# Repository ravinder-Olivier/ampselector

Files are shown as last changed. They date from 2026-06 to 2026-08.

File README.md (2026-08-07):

# Ampselector (Guitar Rig 7 centric macropad)
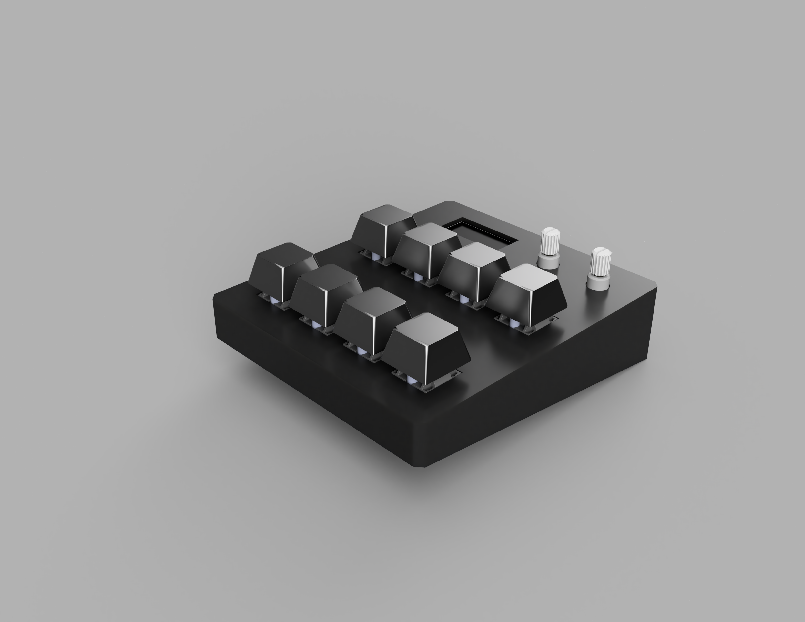
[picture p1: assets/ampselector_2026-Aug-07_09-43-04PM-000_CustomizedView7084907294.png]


Ampselector is a 8 key + two encoder macropad designed to be used for Guitar Rig 7. For actions such as switching between amps or effects presets.

Built using a RP2040 microcontroller in the form of the SEEED STUDIO XIAO, and powered by custom software built on QMK.

## Features: 
- 4x2 grid array
- Dual EC11 microcontrollers
- OLED Display
- Natively outputs MIDI CC codes, and can be programmed into GR7

## CAD / Assembly
- The PCB is screwed *(M3 screw)* onto the lower case with two screws *(into heatset inserts)*
- The top panel is super glued onto the lower case *(sleeker look)*
- Uses MX style keys and keycaps
- This was designed in Fusion360
- Make sure to flash firmware and have it running before you superglue the case together!

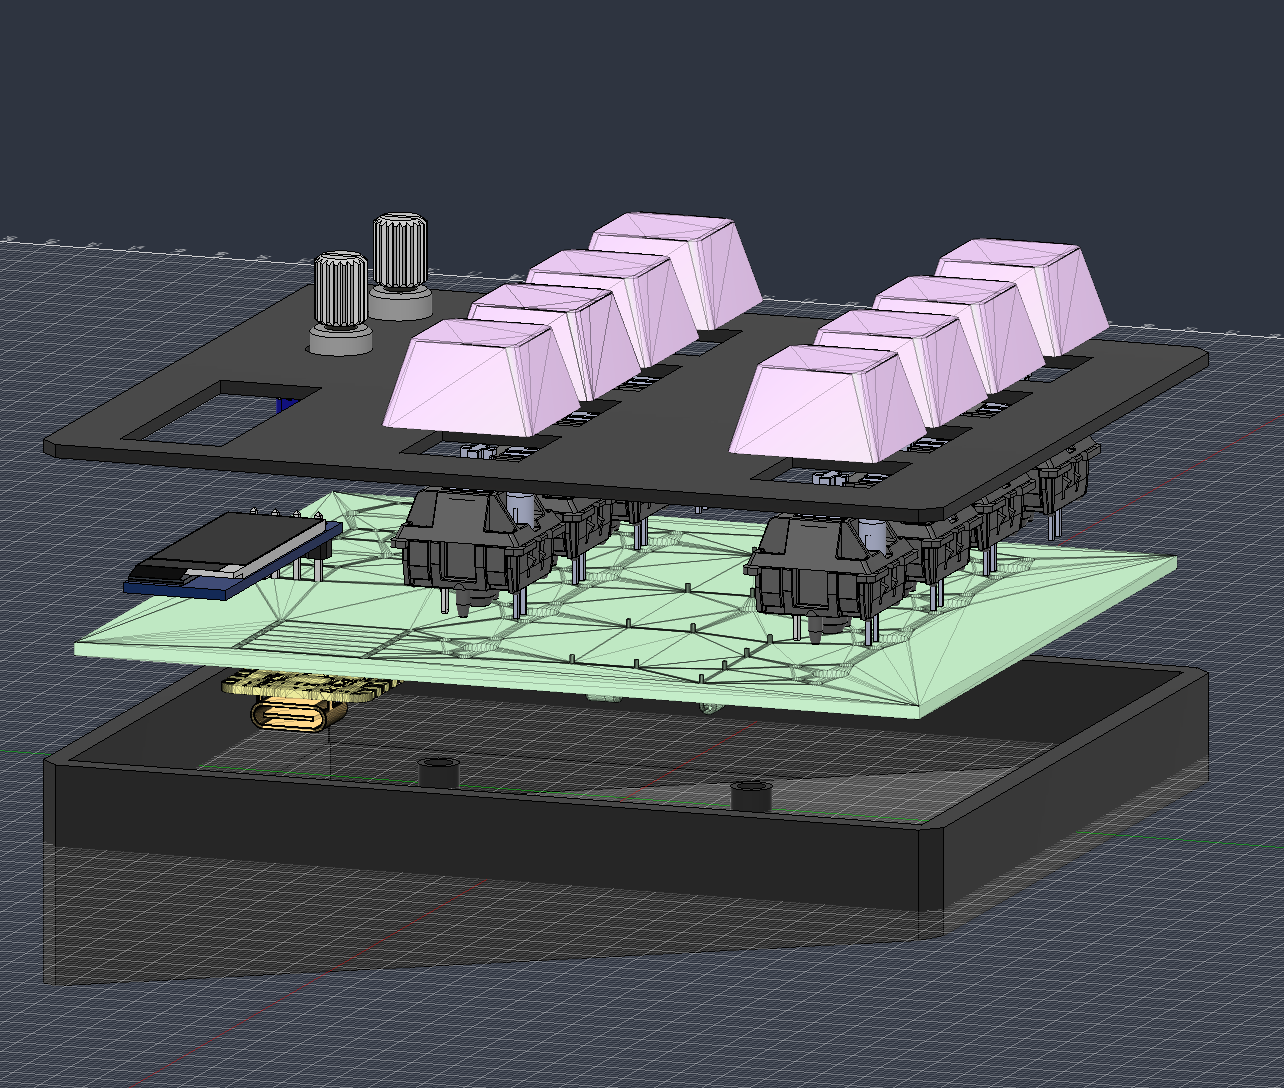
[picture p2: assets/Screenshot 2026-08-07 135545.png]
Screenshot 2026-08-07 135545.png

(note that usb port cutout is not visible in the first image)
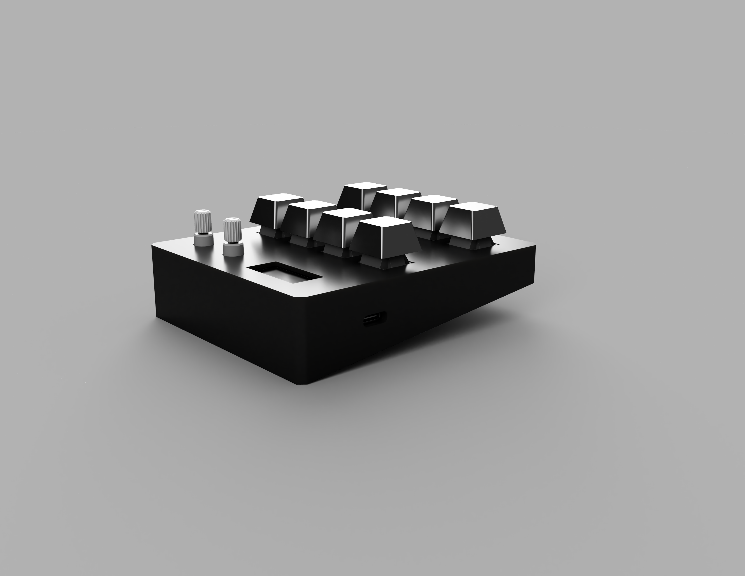
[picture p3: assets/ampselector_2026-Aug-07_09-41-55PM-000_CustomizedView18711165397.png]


## PCB 
- I would recommend buying a thicker style of 2 layer PCB for this project, for the added durability and rigidity
- This was designed in KiCad 

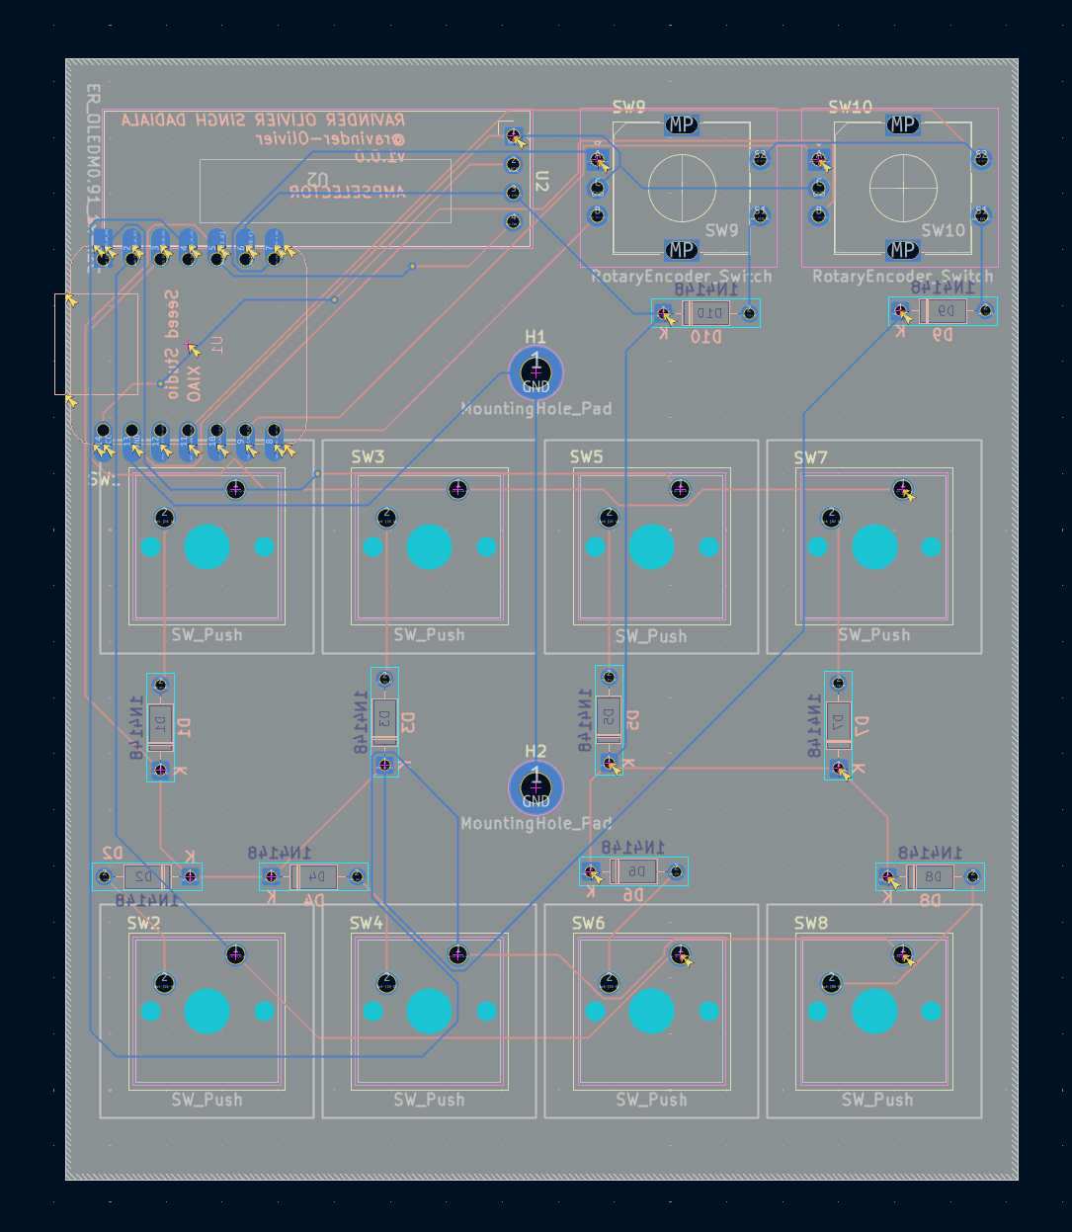
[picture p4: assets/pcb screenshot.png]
pcb screenshot.png

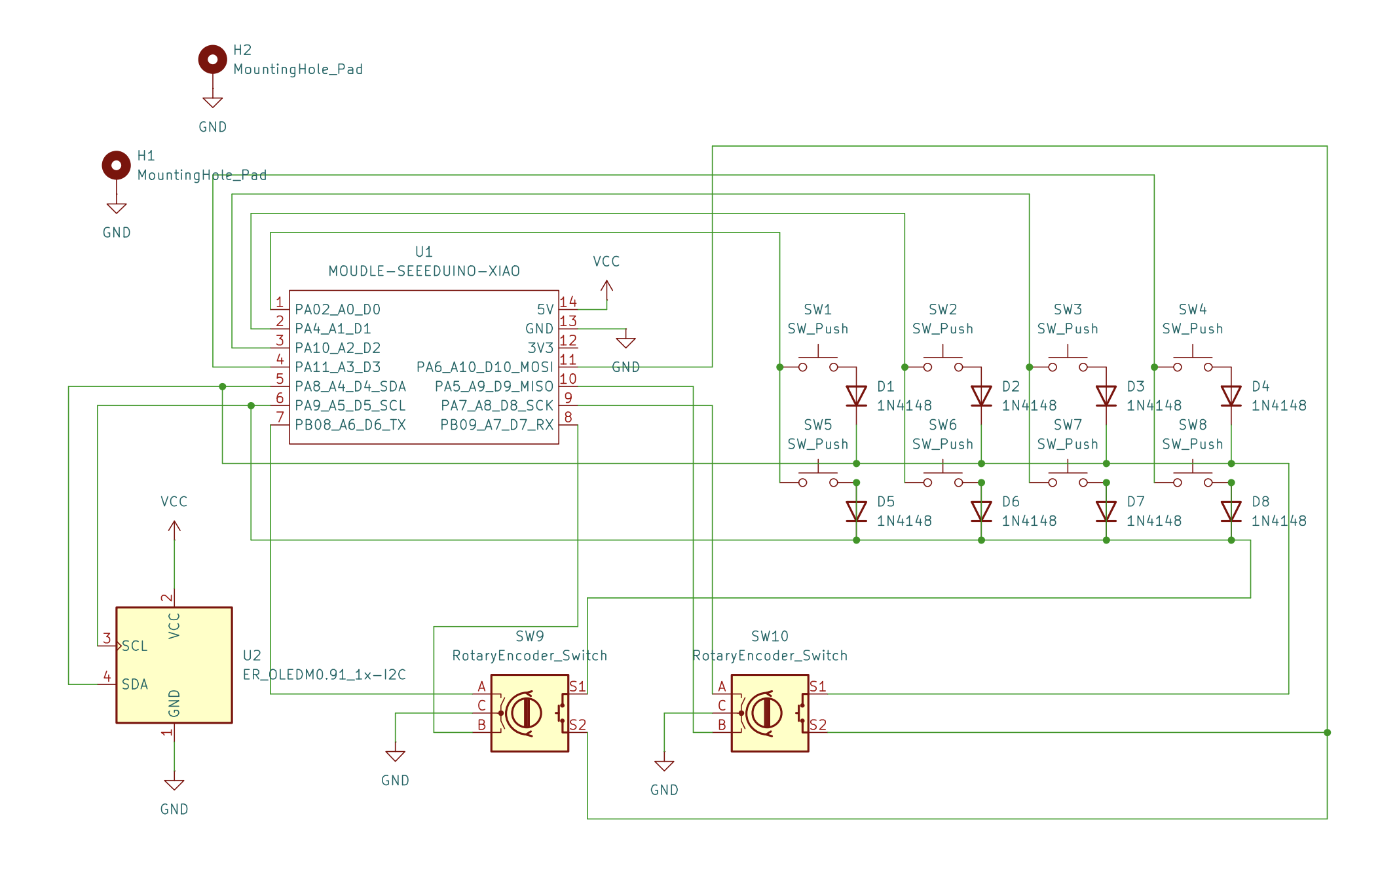
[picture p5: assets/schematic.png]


## BILL OF MATERIALS (BOM)
This project uses:
- 1x Seeed Studio XIAO RP2040
- 8x through hole 1N4148 diodes
- 1x OLED Display (.91in)
- 2x EC11 Rotarary Encoders
- 8x MX Style Keyswitches
- 8x DSA Keycaps
- 2x M3 x 16mm Screws
- 2x M3 Heatset inserts
- 1x PCB (order with gerbers.zip in production)
- 1x Top case (3d print  file in production)
- 1x Bottom case (3d print  file in production)

## Flashing firmware:
- Download the "firmware.uf2" file
- Press and hold the BOOT button on the RP2040 board
- Connect the Data compatible USB cable to the board
- It will appear like a USB drive on your computer, drop the "firmware.uf2" file onto it
- Once it uploads it should disappear as a USB drive, and restart and begin running the QMK firmware!

## Mapping to Guitar Rig 7:
- The keyboard will output various MIDI CC codes, which you can map to various functions in GR7. There's some good info on this forum [thread](https://community.native-instruments.com/discussion/46400/guitar-rig-7-switching-presets-live-with-a-midi-foot-controller)

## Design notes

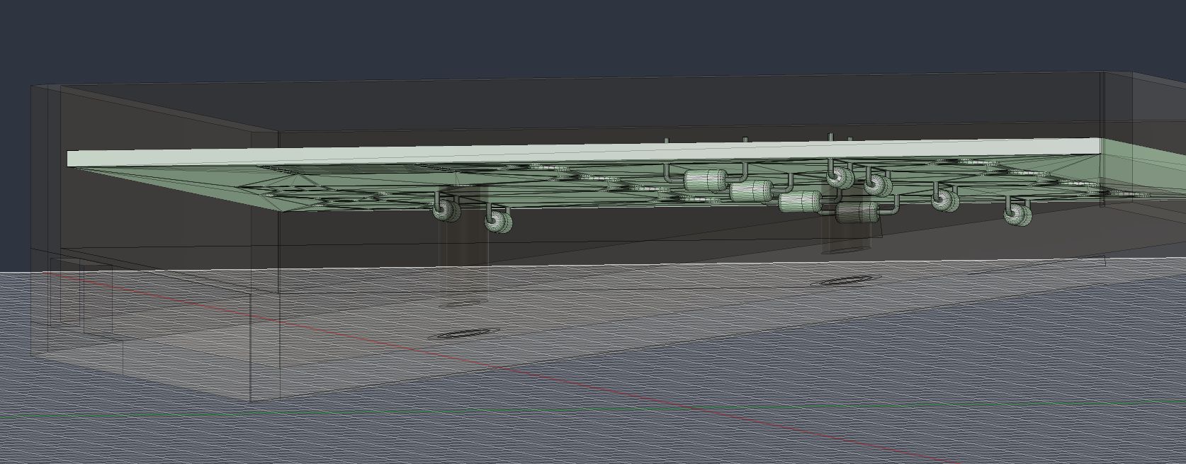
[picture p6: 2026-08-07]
assets/Screenshot 2026-08-07 143020.png

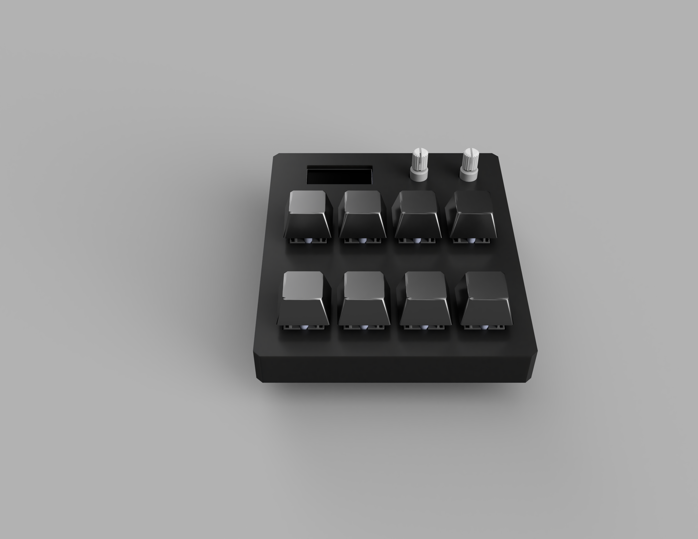
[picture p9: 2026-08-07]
assets/bc9d5303-fcb5-4f72-8860-90336da642d3.PNG

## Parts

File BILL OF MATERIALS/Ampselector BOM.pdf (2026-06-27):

Category | PART | QUANTITY | NOTES
Microcontroller | Seeed Studio XIAO RP2040 | 1
Diodes - through hole | 1N4148 | 8
Display | .91 inch oled display | 1
Encoder | ec11 encoder | 2
Switches | MX style keyswitches | 8
Keycaps | DSA keycaps | 8
Heatset inserts | M3 heatset insert | 2
Screws | m3x16mm screw | 2
Case | Top case | 1 | 3D PRINT
Case | Bottom case | 1 | 3D PRINT
PCB | Ampselector PCB | 1 | Purchase Custom PCB from PCB manufacturer

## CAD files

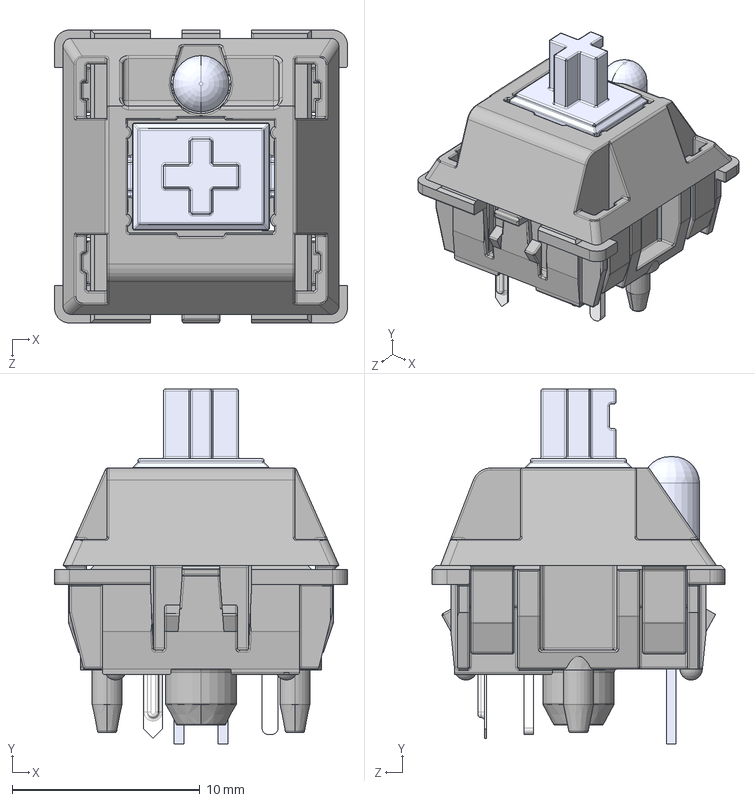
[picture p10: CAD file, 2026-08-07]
CAD/assets/cherry-mx-switch-5.snapshot.2/MX .STEP
15.6 x 18.9 x 15.6 mm
MX 轴 按键′_ü___¨1
MX 轴 轴体áì_¨￠¨__
MX粣 拸簽LEDLEDLED
MX轴 轴体 底部 μ×2__默认_á2____è_
针脚___默认__è_

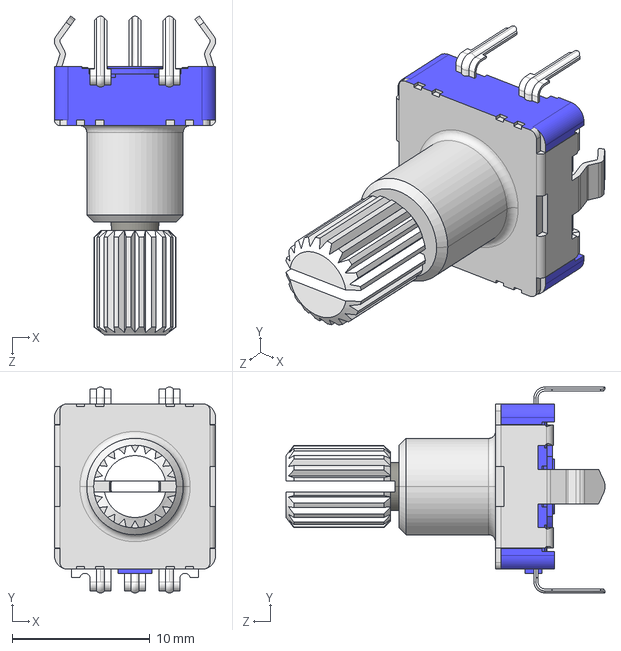
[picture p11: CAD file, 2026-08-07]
CAD/assets/ec11-rotary-encoder-dode-switch-15mm-1.snapshot.1/EC11 Rotary Encoder Dode Switch-15mm .STEP
11.7 x 15.0 x 23.2 mm

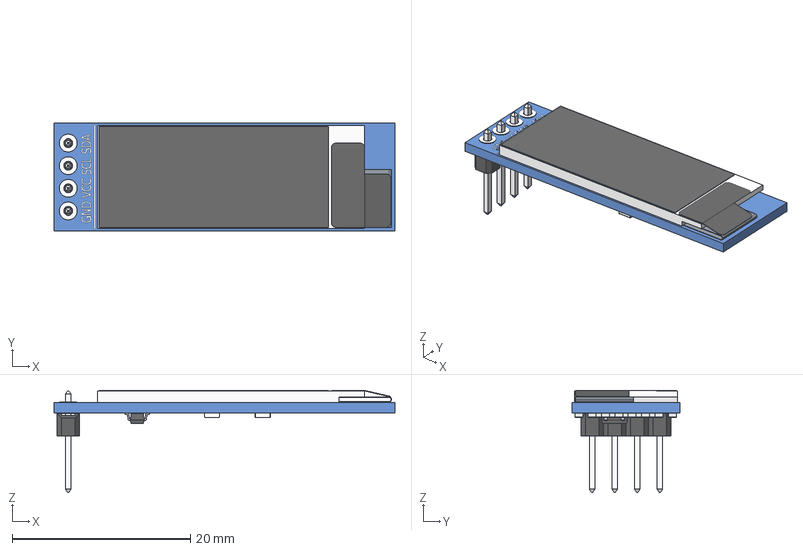
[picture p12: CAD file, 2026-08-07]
CAD/assets/OLED_0.91_128x32.stp
38.3 x 12.1 x 11.5 mm
OLED_0.91_128x32
Pin Header 4 x 1 TH 2.54mm Pitch
RESC-0603 x 13
2SD0601A

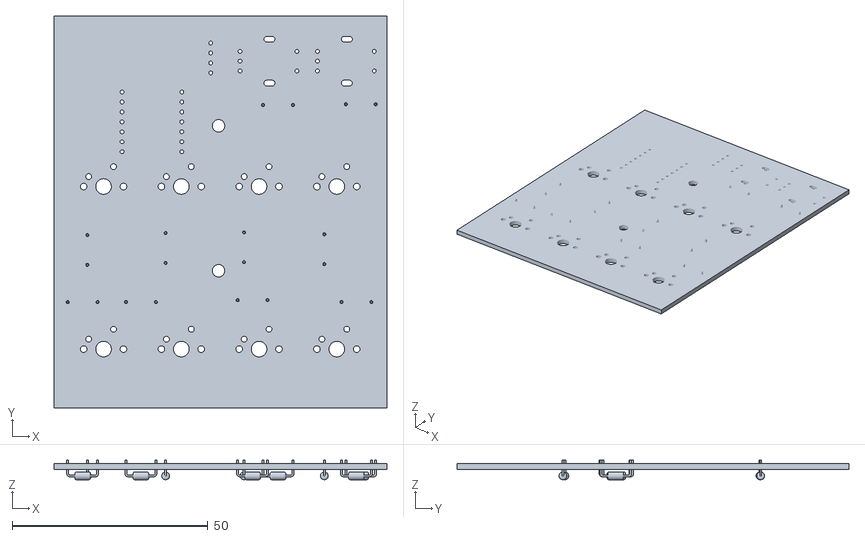
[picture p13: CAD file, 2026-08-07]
CAD/PCB.stl
85.0 x 100.0 x 5.01

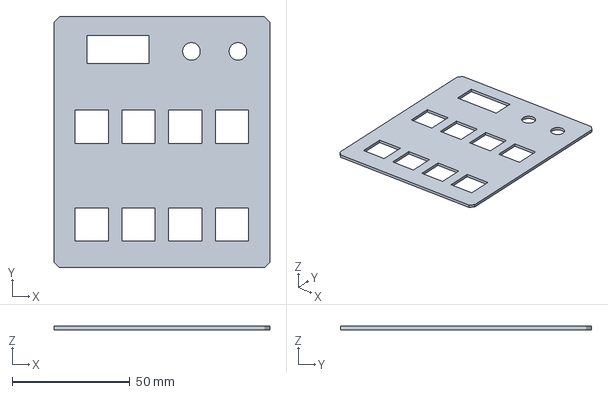
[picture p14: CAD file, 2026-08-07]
Production/Upper Panel.3mf
91.6 x 106.6 x 1.50 mm

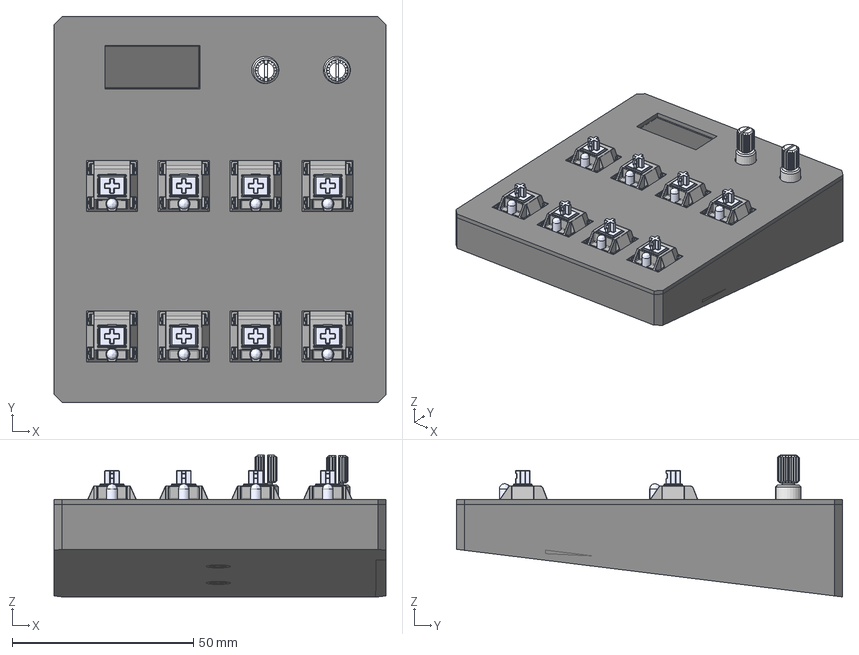
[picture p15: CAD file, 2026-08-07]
CAD/ampselector.step
91.6 x 106.6 x 39.1 mm
Ðý×ª±àÂëÆ÷EC11 E-05SW x 2
MX Öá °´¼ü¡ä_¨¹ ___¡§1 x 8
MX Öá ÖáÌå¨¢¨¬ _¡§¡é¡§__ x 8
MXÖá ÎÞÃ±LEDLEDLED x 8
MXÖá ÖáÌå µ×²¿ ¦Ì¡ Á2__Ä¬ÈÏ_¨¢2____¨¨_ x 8
Õë½Å___Ä¬ÈÏ__¨¨ _ x 8
OLED_0.91_128x32
Pin Header 4 x 1 TH 2.54mm Pitch
RESC-0603 x 13
2SD0601A

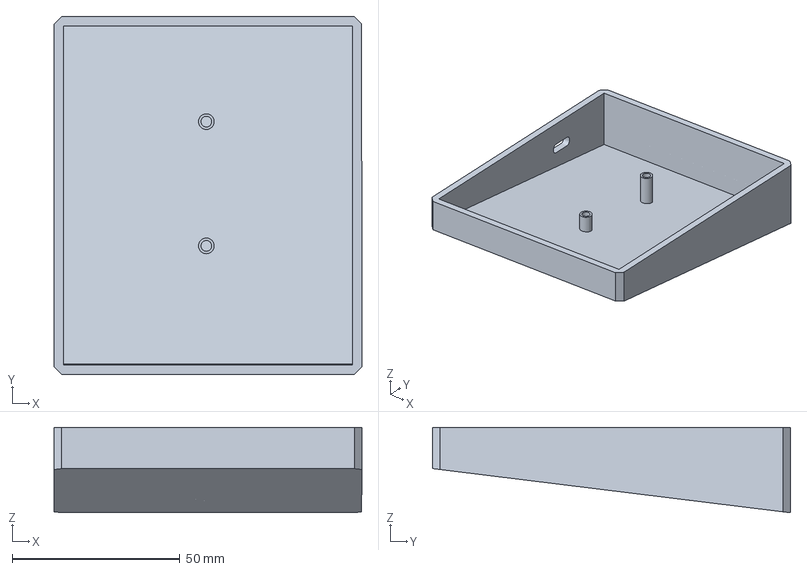
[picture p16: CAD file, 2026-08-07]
Production/Lower Case.3mf
91.6 x 106.6 x 25.4 mm

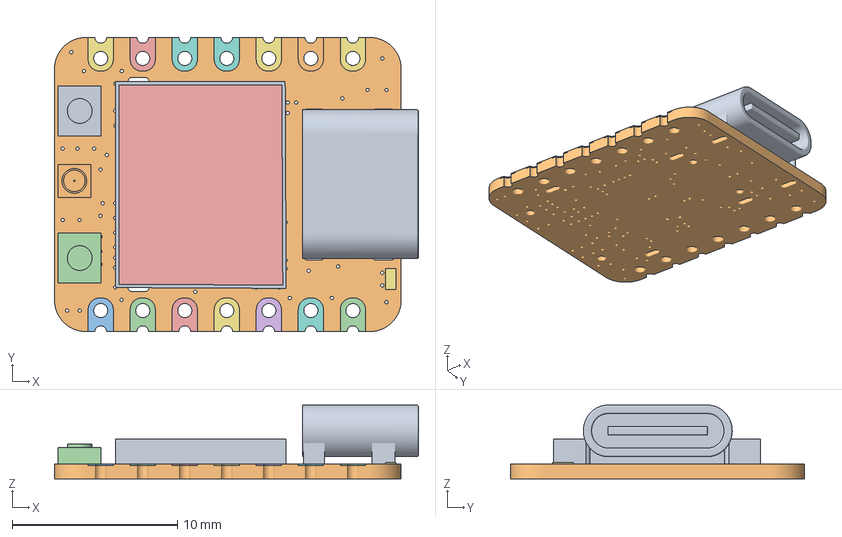
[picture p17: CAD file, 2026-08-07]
CAD/assets/Seeed Studio XIAO ESP32C3.3mf
22.0 x 17.8 x 4.47 mm
Button_B_(Boot?)
C0201
L0201
Button_A_(Reset)
PMOS_1.0*0.6*0.35MM
R0201
SOT-25
USB-C_terminal
R0201_(2)
R0201_(3)
SOD-523
F0603
C0201_(2)
SOT-25_(2)
X2-SMD-1.6X1.0X0.5MM
C0201_(3)
L0201_(2)
C0201_(4)
LED-0402
R0201_(4)
C0201_(5)
C0201_(6)
C0201_(7)
R0201_(5)
C0201_(8)
QFN32G-0.5-5X5MM
C0201_(9)
C0201_(10)
C0201_(11)
C0201_(12)
C0201_(13)
C0201_(14)
R0201_(6)
C0201_(15)
C0201_(16)
R0201_(7)
C0201_(17)
C0201_(18)
C0201_(19)
R0201_(8)
C0201_(20)
C0201_(21)
C0201_(22)
X4-SMD-2.0X1.6X0.5MM
C0201_(23)
C0201_(24)
C0201_(25)
R0201_(9)
C0201_(26)
C0201_(27)
R0201_(10)
C0201_(28)
R0201_(11)
R0201_(12)
R0201_(13)
R0201_(14)
Board

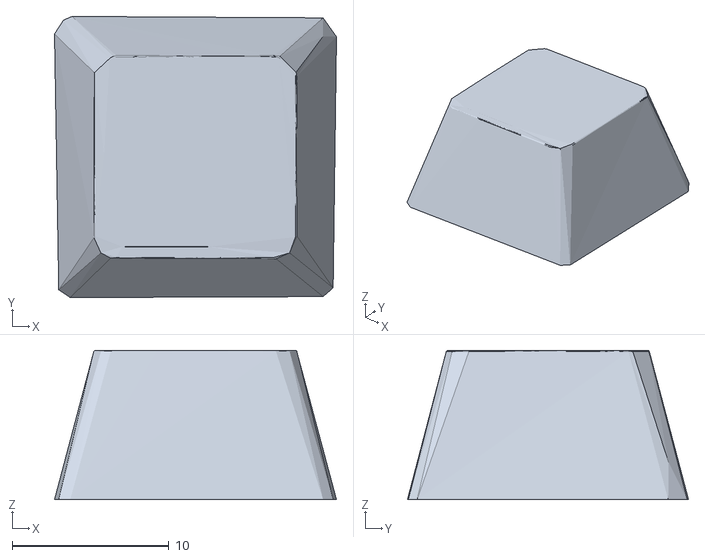
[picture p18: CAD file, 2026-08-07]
CAD/assets/Simple-CherryMX-Keycap.stl
18.0 x 17.9 x 9.50

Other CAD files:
CAD/assets/newpcb.step
CAD/ampselector.f3z
CAD/assets/newpcb.stl

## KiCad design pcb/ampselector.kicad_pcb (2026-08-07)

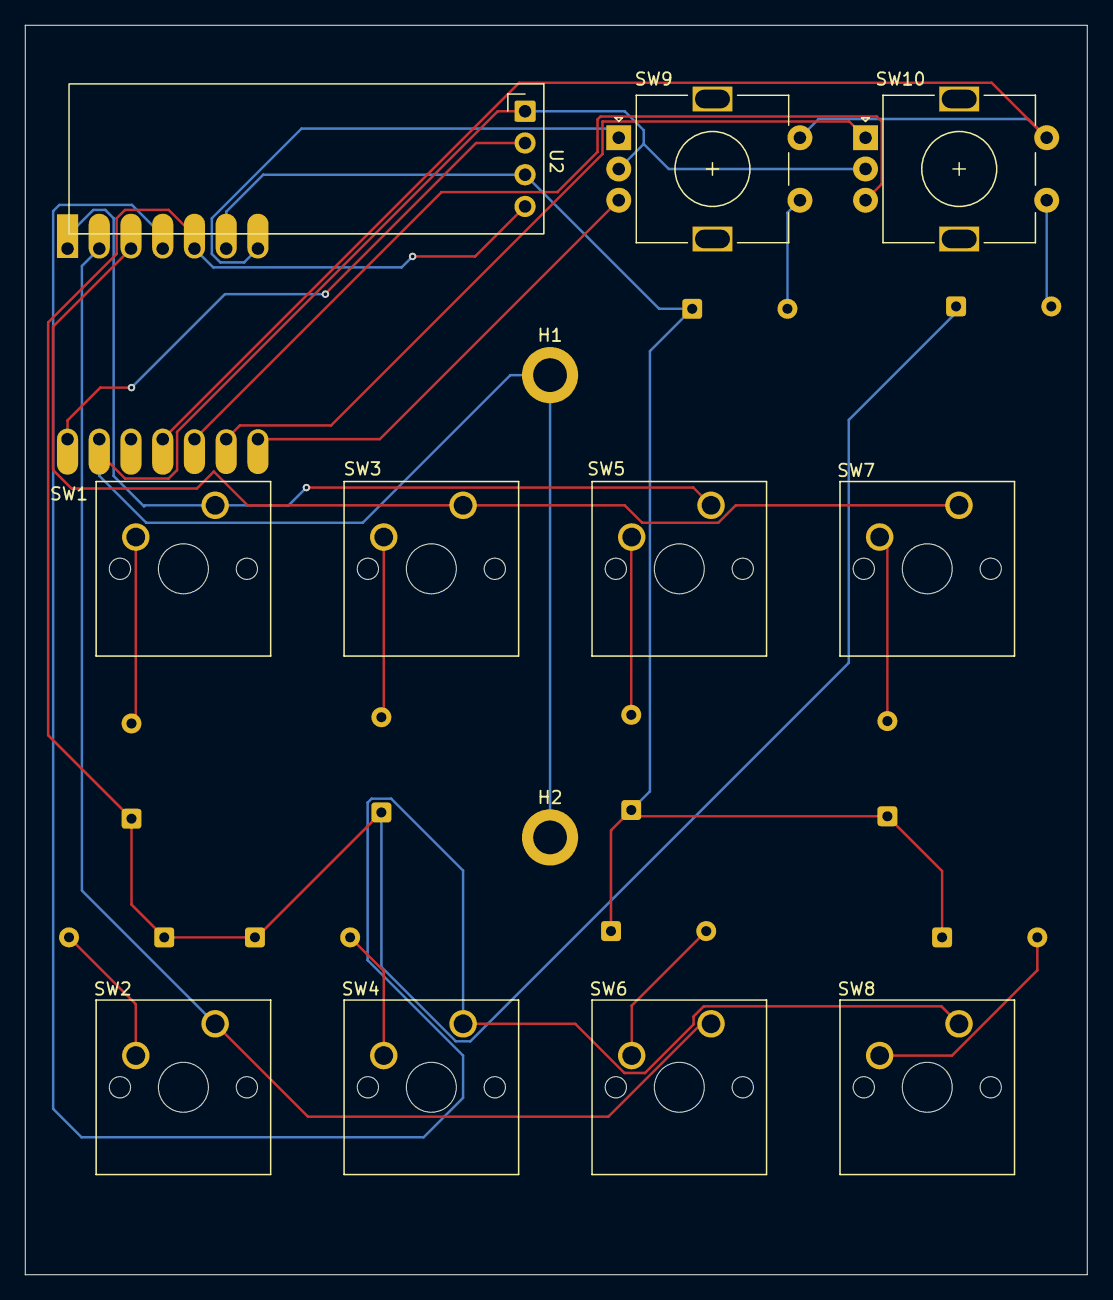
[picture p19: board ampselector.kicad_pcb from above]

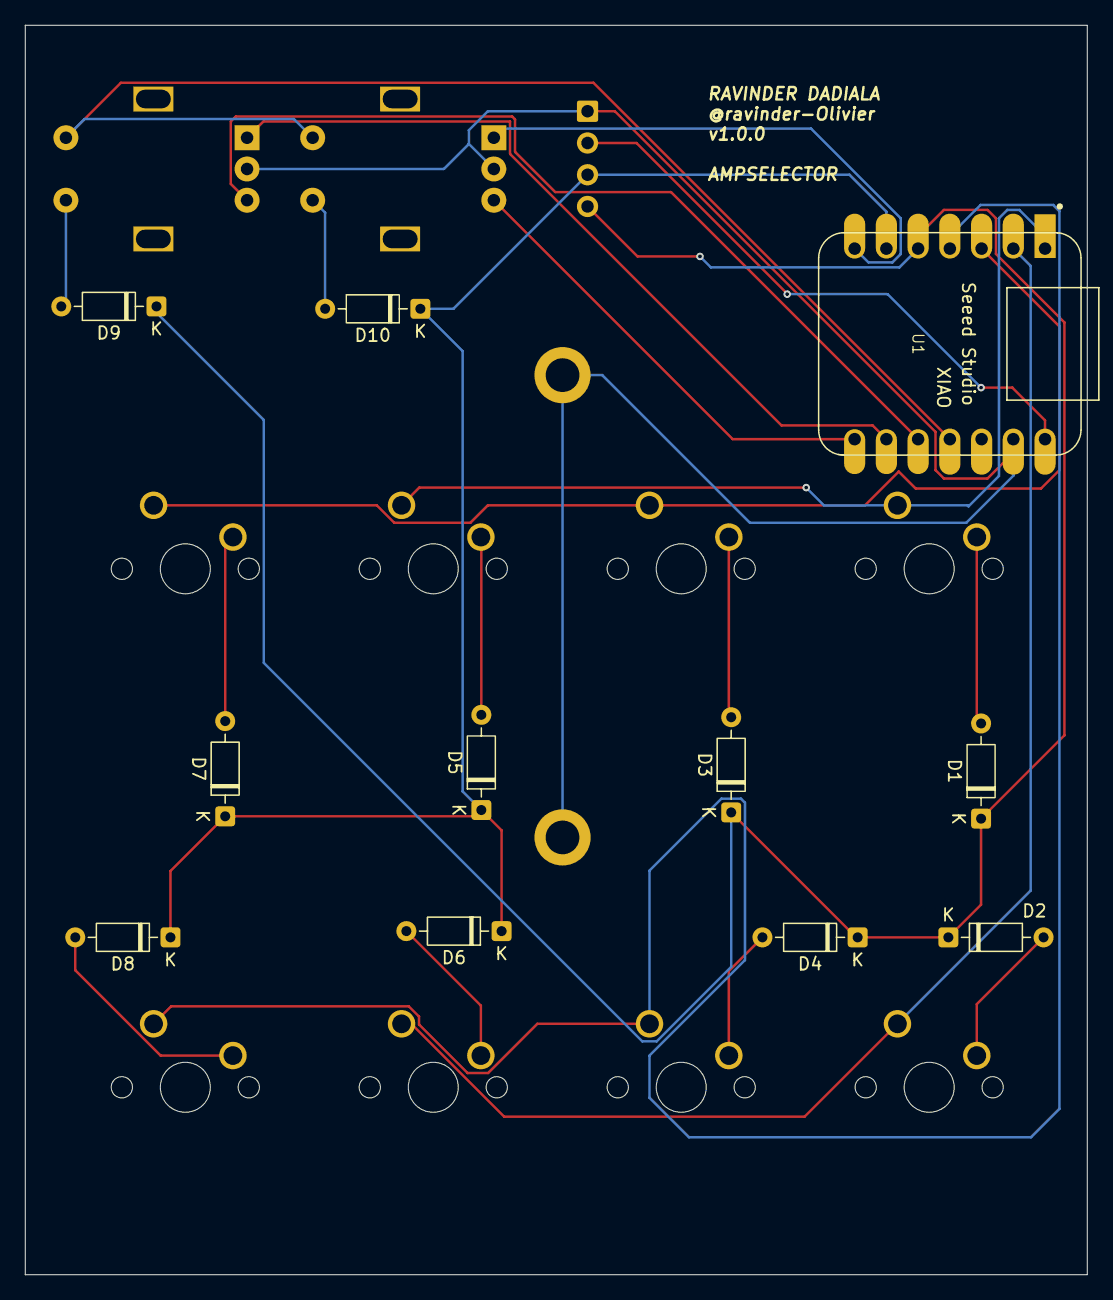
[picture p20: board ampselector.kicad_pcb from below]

Board: 2 copper layers, 85.0 x 100.0 mm, 24 parts (11 on the bottom side), 23 nets.

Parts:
D1, D2, D3, D4, D5, D6, D7, D8, D9, D10: 1N4148; D_DO-35_SOD27_P7.62mm_Horizontal
H1, H2: MountingHole_Pad; MountingHole_2.7mm_M2.5_ISO7380_Pad
SW1, SW2, SW3, SW4, SW5, SW6, SW7, SW8: SW_Push; SW_Cherry_MX_1.00u_PCB
SW9, SW10: RotaryEncoder_Switch; RotaryEncoder_Alps_EC11E-Switch_Vertical_H20mm
U1: MOUDLE-SEEEDUINO-XIAO; XIAO-Generic-Hybrid-14P-2.54-21X17.8MM
U2: ER_OLEDM0.91_1x-I2C

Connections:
GND: H1.1 (1_1), H2.1 (1_1), SW9.C, SW10.C, U1.13 (GND), U2.1 (GND)
unnamed: D1.2 (A), SW1.2
unnamed: D1.1 (K), D2.1 (K), D3.1 (K), D4.1 (K), D9.1 (K), U1.5 (PA8_A4_D4_SDA), U2.4 (SDA)
unnamed: D2.2 (A), SW2.2
unnamed: D3.2 (A), SW3.2
unnamed: D4.2 (A), SW4.2
unnamed: D5.2 (A), SW5.2
unnamed: D6.2 (A), SW6.2
unnamed: D7.2 (A), SW7.2
unnamed: D8.2 (A), SW8.2
unnamed: D9.2 (A), SW10.S1
unnamed: D10.2 (A), SW9.S1
unnamed: D5.1 (K), D6.1 (K), D7.1 (K), D8.1 (K), D10.1 (K), U1.6 (PA9_A5_D5_SCL), U2.3 (SCL)
unnamed: SW1.1, SW5.1, U1.1 (PA02_A0_D0)
unnamed: SW2.1, SW6.1, U1.2 (PA4_A1_D1)
unnamed: SW10.B, U1.10 (PA5_A9_D9_MISO)
unnamed: SW9.S2, SW10.S2, U1.11 (PA6_A10_D10_MOSI)
unnamed: SW10.A, U1.9 (PA7_A8_D8_SCK)
unnamed: SW3.1, SW7.1, U1.3 (PA10_A2_D2)
unnamed: SW4.1, SW8.1, U1.4 (PA11_A3_D3)
unnamed: SW9.A, U1.7 (PB08_A6_D6_TX)
unnamed: SW9.B, U1.8 (PB09_A7_D7_RX)
VCC: U1.14 (5V), U2.2 (VCC)

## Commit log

2026-06-13 Folder org
    [ampselector WITH DIODES.kicad_sch, ampselector-LENGTHWISE.kicad_pcb, ampselector.kicad_pcb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]
2026-06-13 added gitignore
    [ampselector WITH DIODES.kicad_sch, ampselector-LENGTHWISE.kicad_pcb, ampselector.kicad_pcb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]
2026-06-13 Initialize README with project details and images
    Added project description and PCB format images to README.
2026-06-13 fixed incorrect pins for matrix wiring
2026-06-14 encoder map func
2026-06-14 UPDATED PIN REFERENCES
2026-06-17 Designed Case
    [Lower Case.3mf, Upper Panel.3mf, ampselector-LENGTHWISE.kicad_pcb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]
2026-06-17 production/dir updates
    [Lower Case.3mf, Upper Panel.3mf, ampselector.3mf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]
2026-06-17 Exported gerbers.zip
2026-06-17 Added silkscreen
    [ampselector.kicad_pcb]
2026-06-17 Add Bill of Materials to README
    Added a Bill of Materials section listing required components for the project.
2026-06-17 Updated folder structure to be suitable
    [ampselector.f3d]
2026-06-18 MAJOR SILKSCREEN FIX
    [ampselector.f3d]
2026-06-20 changed text layer on silkscreen
    [ampselector.kicad_pcb]
2026-06-27 Added BOM
    [Ampselector BOM.xlsx]
2026-07-02 updated images for pcb
    with routed versions
2026-08-05 FOLDER ORG UPDATES
    [Ampselector BOM.xlsx]
2026-08-07 updates to PCB and case and general design
    [Ampselector BOM.xlsx, ampselector.kicad_pcb]
2026-08-07 Updated gerbers.zip
2026-08-07 updated readme with schematic photo
2026-08-07 Updated readme with schematic image
